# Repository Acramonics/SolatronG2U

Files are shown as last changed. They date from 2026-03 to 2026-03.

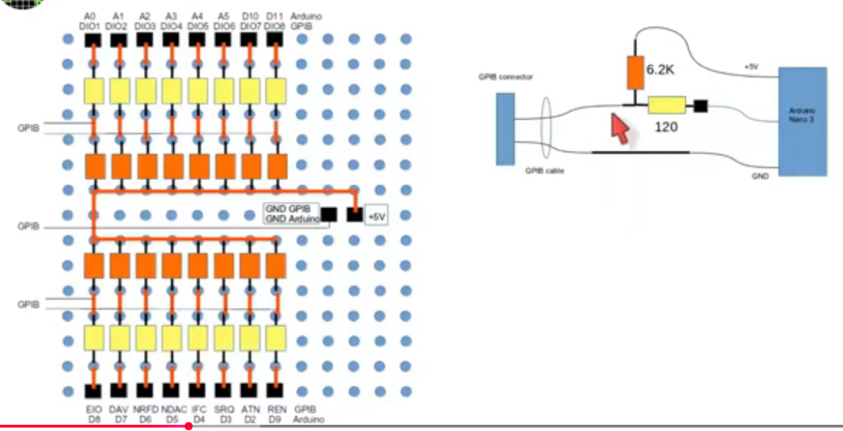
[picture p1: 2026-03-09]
SourceImages/Circuit.png

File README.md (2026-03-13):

G2U
===

Andrew Martin, acramonics, 2026
-------------------------------

`G2U` is a PCB for a GPIB to USB adapter using an Arduino Nano 3.

GPIB is a vendor-neutral interface for controlling equipment and
logging data. While rather outdated, and largely replaced by USB and
Ethernet, some equipment still uses it and there are many second hand
devices (such as multimeters) that use it including the well-regarded
Solartron 7150+.

A video on GPIB (also known as IEEE-488) is on
[YouTube](https://www.youtube.com/watch?v=EEtETGfL_VE) and details are
on [Wikipedia](https://en.wikipedia.org/wiki/GPIB).

### Hardware

The original circuit and software was by Rudolf Reuter and modified by
@TheHWCave. Rudolf's blog, where this was described, doesn't seem to
be available any more (as of March 2026), but @TheHWCave provides a
detailed description of the circuit on
[YouTube](https://www.youtube.com/watch?v=RaLirRvSngk) (see the
screenshots in the `SourceImages` directory).  He builds it on
stripboard and uses an Arduino breakout board, so I decided to create
a PCB instead. He was unable to obtain a PCB-mounted Centronics-style
(*Series 57*) 24-pin connector. These are now easily available from
AliExpress (at about £2.50 with free postage if you spend more than
£8.00), and I have used a PCB-mounted male connector that can plug
straight into the back of the hardware, so you don't need to worry
about cables.

There is another page with a [discussion of creating a GPIB/USB
interface](https://egirland.blogspot.com/2014/03/arduino-uno-as-usb-to-gpib-controller.html),
but note that this uses different pin assignments and different
software.

### Software

@TheHWCave provides the code for the Arduino Nano 3 and a logger
script on [GitHub](https://github.com/TheHWcave/GPIB-to-USB).

He provides an [update
video](https://www.youtube.com/watch?v=DAS1KVU_FaA) which explains how
to address a problem with the Arduino losing its software when the USB
us disconnected, but the GPIB connection is still present. The GPIB
seems to provide some partial power to the Arduino and he provides
instructions on setting a brown-out fuse in software.

I provide a summary of all the necessary information on this page.

The PCB
-------

As is often the case with my PCBs, you will require my
`ACRM_KiCad_Libs` to provide the footprint for the 24-pin male
Centronics-style connector. You will need a version from March 2026 or
later.

Bill of Materials
-----------------

- Arduino ATmega Nano 3.x with USB (ideally USB-C) [1 off]
- 6K2 0.25W resistors (R1-R16) [16 off]
- 120R 0.25W resistors (R17-R32) [16 off]
- Centronics-style 24P 'Series 57' male connector [1 off]

The PCB is 78.05mm x 71.40mm so you will need a plastic case to
accomodate this.  The Centronics-style connector projects from the
board so will need a suitable cutout. The USB connector is set back on
the board, so it's not easy to plug a cable in and out once the board
is in the case, but, since the GPIB sockets are usually at the back of
equipment, the expectation is that the board and the cable will be
left plugged in.

Ardunio to GPIB connections
---------------------------

This table is expanded from a table shown in @TheHWCave's video (see
the screenshot in the `SourceImages` directory) and shows which
connections from the Arduino go to which pins on the GPIB. The Arduino
pins are shown with the pin number (from 1-30) and the position on the
left (L) or right (R) column of pins - both counting from the top.

| Arduino Line | Arduino Pin | | GPIB Pin | Function | ATmega328P |
|---|---|-----|---|---|---|
| A0 | 19/R12 | --- | 1 | DIO1 | (PC0/ADC0) |
| A1 | 20/R11 | --- | 2 | DIO2 | (CP1/ADC1) |
| A2 | 21/R10 | --- | 3 | DIO3 | (PC2/ADC2) |
| A3 | 22/R9 | --- | 4 | DIO4 | (PC3/ADC3) |
| A4 | 23/R8 | --- | 13 | DIO5 | (PC4/ADC4) |
| A5 | 24/R7 | --- | 14 | DIO6 | (PC5/ADC5) |
| D10 | 13/L13 | --- | 15 | DIO7 | (PB2) |
| D11 | 14/L14 | --- | 16 | DIO8 | (PB3(MOSI)) |
| D8 | 11/L11 | --- | 5 | EIO | (PB0) |
| D7 | 10/L10 | --- | 6 | DAV | (PD7) |
| D6 |  9/L9 | --- | 7 | NRFD | (PD6) |
| D5 |  8/L8 | --- | 8 | NDAC | (PD5) |
| D4 |  7/L7 | --- | 9 | IFC | (PD4) |
| D3 |  6/L6 | --- | 10 | SRQ | (PD3) |
| D2 |  5/L5 | --- | 11 | ATN | (PD2) |
| D9 | 12/L12 | --- | 17 | REN | (PB1) |
| GND |  4/L4 | --- | 12,18-24 | GND | |
| GND | 29/R2 | --- | 12,18-24 | GND | |
| +5V | 27/R4 | +5V | | | |
| D1/TX1 |  1/L1 | NC  | | | |
| RX0 |  2/L2 | NC  | | | |
| RESET |  3/L3 | NC  | | | |
| D12 | 15/L15 | NC  | | | |
| VIN | 30/R1 | NC  | | | |
| RESET2 | 28/R3 | NC  | | | |
| A7 | 26/R5 | NC  | | | |
| A6 | 25/R6 | NC  | | | |
| AREF | 18/R13 | NC  | | | |
| +3V3 | 17/R14 | NC  | | | |
| D13 | 16/R15 | NC  | | | |

Note that each GND pin in the GPIB connector is paired with one of the
data lines in a twisted pair. Pin 12 is connected to the cable shield.
See [GPIB on WikiPedia](https://en.wikipedia.org/wiki/GPIB). In this
application, this is rather irrelevant as everything is connected to a
common ground.

The Brown-Out Fuse
------------------

As described above, @TheHWCave provides an [update
video](https://www.youtube.com/watch?v=DAS1KVU_FaA) which explains how
to set the 'brown-out fuse' on the Arduino to prevent it losing its
software.

The 'extended fuse byte' has three bits that set the Brown-Out
Detector voltage level ('BODLEVEL'). When the voltage falls below
this, the chip is disabled.

|Extended Fuse Byte | Bit No | Default Value |
|---|---|---|
|- | 7 | 1 |
|- | 6 | 1 |
|- | 5 | 1 |
|- | 4 | 1 |
|- | 3 | 1 |
|BODLEVEL2 | 2 | 1 (unset) |
|BODLEVEL1 | 1 | 1 (unset) |
|BODLEVEL0 | 0 | 1 (unset) |

The values for the BODLEVEL bits are as follows:

|BODLEVEL 2:0 Fuses | Hex (*)  | Min V | Typ V | Max V | Units |
|---|---|---|---|---|---|
|111 | 0x07 | Off | Off | Off | |
|110 | 0x06 | 1.7 | 1.8 | 2.0 | V |
|101 | 0x05 | 2.5 | 2.7 | 2.9 | V |
|100 | 0x04 | 4.1 | 4.3 | 4.5 | V |
|011 | 0x03 | Reserved | Reserved | Reserved | |
|010 | 0x02 | Reserved | Reserved | Reserved | |
|001 | 0x01 | Reserved | Reserved | Reserved | |
|000 | 0x00 | Reserved | Reserved | Reserved | |

(*) Since bits 3 to 7 are not used, these can all be set to zero and
the Hex values reflect that.

By default the fuse is set to #FF, the BODLEVEL bits are therefore set
to binary 111 which means the brown-out fuse is switched off.

@TheHWCave selects a BODLEVEL of 4.1V (minimal) so sets the
fuse to binary 100 (#04) for 4.1V cutoff.

Instructions on how to do this are provided below.

Software Installation
---------------------

You will need:

- A USB cable to connect your computer to your Arduino Nano
- An ICSP programmer with a 6-pin header adapter to connect to the
  Nano.  There are instructions online to use another Arduino for this
  purpose or you can buy a standalone programmer such as the USBASP
  programmers available from Amazon (amongst other places).

You will need the software available from
https://github.com/TheHWcave/GPIB-to-USB

Using this is explained in the video at
https://www.youtube.com/watch?v=RaLirRvSngk

### Step 1: The Arduino IDE

Install the Arduino IDE as described on the [Arduino Web
Site](https://support.arduino.cc/hc/en-us/articles/360019833020-Download-and-install-Arduino-IDE)

### Step 2: Configure the IDE for the Arduino Nano ATmega chip you are using [OPTIONAL]

Different Arduinos use different chips which have different signature
bytes and this needs to match the programmer:

Chip        | Byte 0x000 | Byte 0x001 | Byte 0x002
------------|------------|------------|------------
ATmega328   | 0x1E       | 0x95       | 0x14
ATmega328P  | 0x1E       | 0x95       | 0x0F
ATmega328PB | 0x1E       | 0x95       | 0x16

If the configuration doesn't match your chip then, for example, the
Arduino IDE may call AVRDude (used to set the fuse) expecting to find
an ATmega328P, but AVRDude finds an ATmega328PB and stops.

The configuration can be set in a configuration file or by manually
re-running the failed command, but correcting for the appropriate
chip. (See instructions below.)

If using Linux, the easest thing to do is create configuration file:
`~/.avrduderc` containing:

```
part parent "m328"
    id                  = "m328p";
    desc                = "ATmega328P";
    signature           = 0x1e 0x95 0x14;
    ocdrev              = 1;
;
```
setting the `id`, `desc` and `signature` as required depending on what
ATmega chip you have with signature bytes set as per the table above.

Alternatively you can allow AVRDude from the IDE to fail and then run
the fixed command manually as described below.

### Step 3: Setting the Brown-Out Fuse

*I will write a more detailed version when I have verified this on a
couple of Arduino Nano boards. This is largely in note form!*

As described above, you will need a second Arduino, or an ICSP
programmer spported by the Arduino IDE, to set the fuse. The IDE runs
the AVRDude software to perform the programming of the Brown-Out Fuse.

*To set the fuse from the Arduino IDE, proceed as follows --- to be written*

See:
- https://forum.arduino.cc/t/is-there-brown-out-detection-for-arduino-uno/124777/18
- https://electronics.stackexchange.com/questions/229189/atmega328p-how-is-brown-out-detection-supposed-to-work
- https://forum.arduino.cc/t/unable-to-set-fuses-on-atmega328p-using-avrdude-in-command-prompt-windows/1067499/5

Set the IDE to run in verbose mode so you can see what it is doing as
[described
here](https://support.arduino.cc/hc/en-us/articles/4407705216274-Use-verbose-output-in-the-Arduino-IDE)

If you have configured the IDE properly, then it should work with no
errors.  If you haven't then the AVRDude software will fail since the
chip's signature doesn't match what the software expected. The
workaround for this is described in @TheHWCave's video at
https://www.youtube.com/watch?v=DAS1KVU_FaA and summarized below.

If AVRDude fails, simply copy the failed command from the upload
window and run it from the command line instead, correcting the
errornous chip type. For example, assuming the Arduino IDE is
configured for an ATmega328P and your Nano has an ATmega328PM and
assuming that the IDE is installed in a directory pointed to by the
environment variable `$ARDUINO` (e.g. `$HOME/arduino-1.8.9`), you
might see the failed command to be:

```
$ARDUINO/hardware/tools/avr/bin/avrdude \
   -C$ARDUINO/hardware/tools/avr/etc/avrdude.conf \
   -v -patmega328p \
   -cusbasp -Pusb -e -Ulock:w:0x3F:m -Uefuse:w:0xF4:m \
   -Uhfuse:w:0xDA:m -Ulfuse:w:0xFF:m
```
and you would modify this to
```
$ARDUINO/hardware/tools/avr/bin/avrdude \
   -C$ARDUINO/hardware/tools/avr/etc/avrdude.conf \
   -v -patmega328pb \
   -cusbasp -Pusb -e -Ulock:w:0x3F:m -Uefuse:w:0xF4:m \
   -Uhfuse:w:0xDA:m -Ulfuse:w:0xFF:m
```
(note the change in the 3rd line) and run it from the command line

### Step 4: Restoring the bootloader

Setting the fuse erases the memory, so you then need to restore the bootloader.

Instructions on doing this from the IDE are [described here](https://support.arduino.cc/hc/en-us/articles/4841602539164-Burn-the-bootloader-on-UNO-Mega-and-classic-Nano-using-another-Arduino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)

Alternatively, you can do it from the command line using AVRDude:

```
~/arduino-1.8.9/hardware/tools/avr/bin/avrdude \
   -C~/arduino-1.8.9/hardware/tools/avr/etc/avrdude.conf \
   -v -patmega328pb \
   -cusbasp -Pusb -Uflash:w:./optiboot_atmega328.hex
```

This also allows the latest bootloader to be downloaded and installed.
See

- https://forum.arduino.cc/t/how-do-i-install-optiboot-on-the-newest-arduino-ide/345443
- https://github.com/Optiboot/optiboot

(The latest, as of March 2026, is
https://github.com/Optiboot/optiboot/releases/download/v8.0/package_optiboot_optiboot-additional_index.json)

### Step 5: Installing the Arduino software

You can then remove the in-circuit programmer and upload the
GPIB-to-USB software sketch in the normal way from the Arduino IDE
through the USB cable and with the newly installed boot loader.

*To be written.*

Future plans
------------

In future, I may do an SMD version to minimize the size and weight!

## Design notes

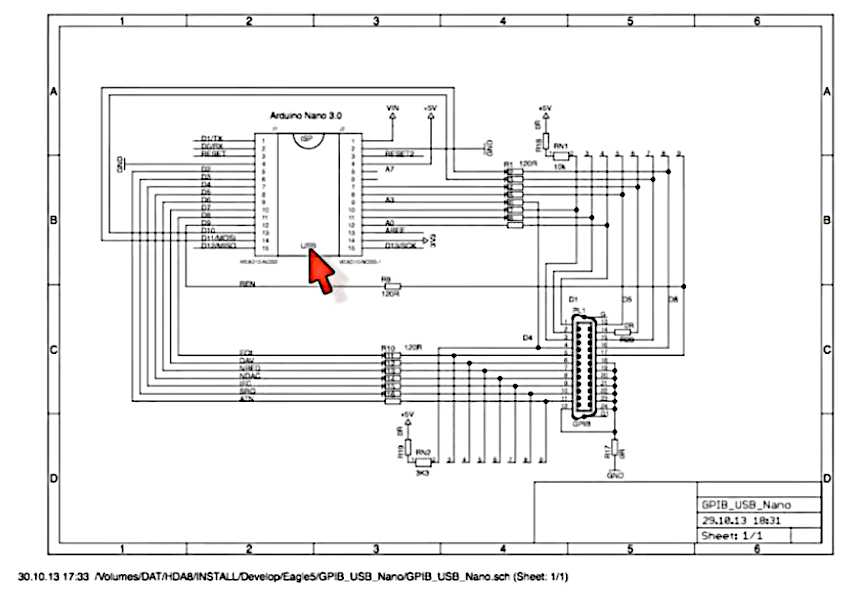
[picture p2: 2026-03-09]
SourceImages/Schematic.png

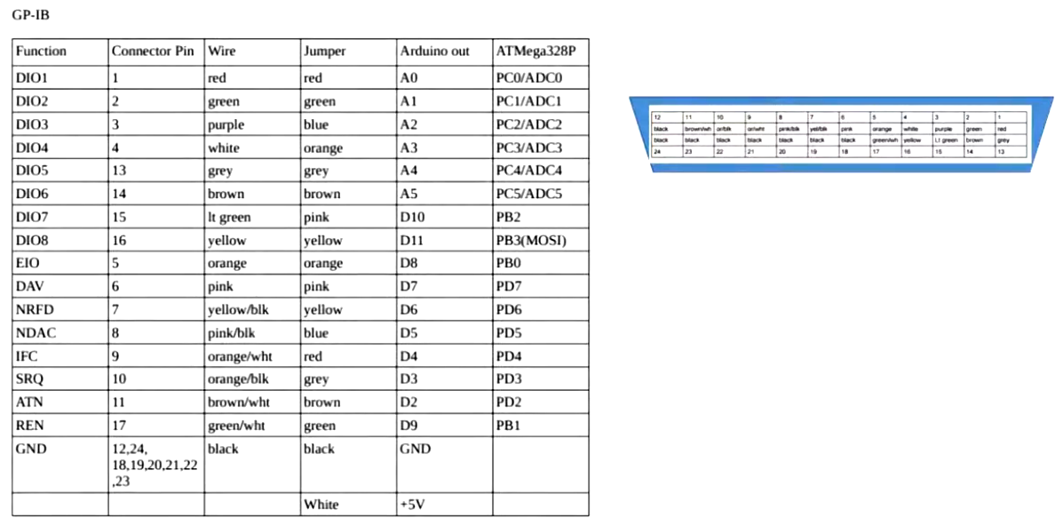
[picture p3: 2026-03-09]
SourceImages/ConnectionTable.png

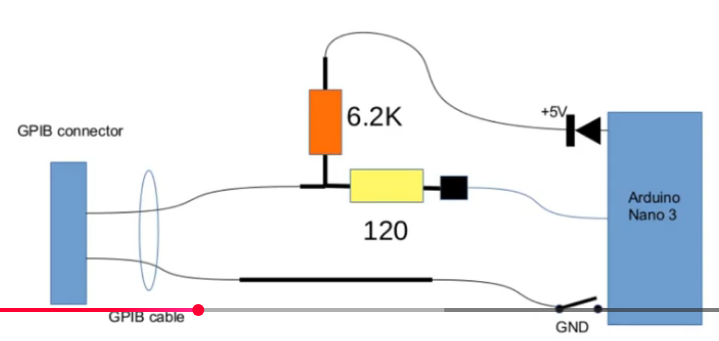
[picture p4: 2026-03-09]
SourceImages/DiodeAndSwitch.png

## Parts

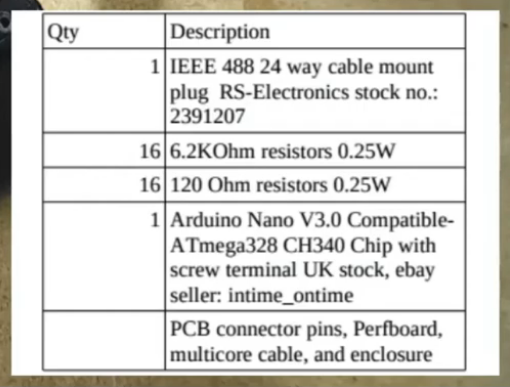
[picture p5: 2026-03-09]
SourceImages/BOM.png

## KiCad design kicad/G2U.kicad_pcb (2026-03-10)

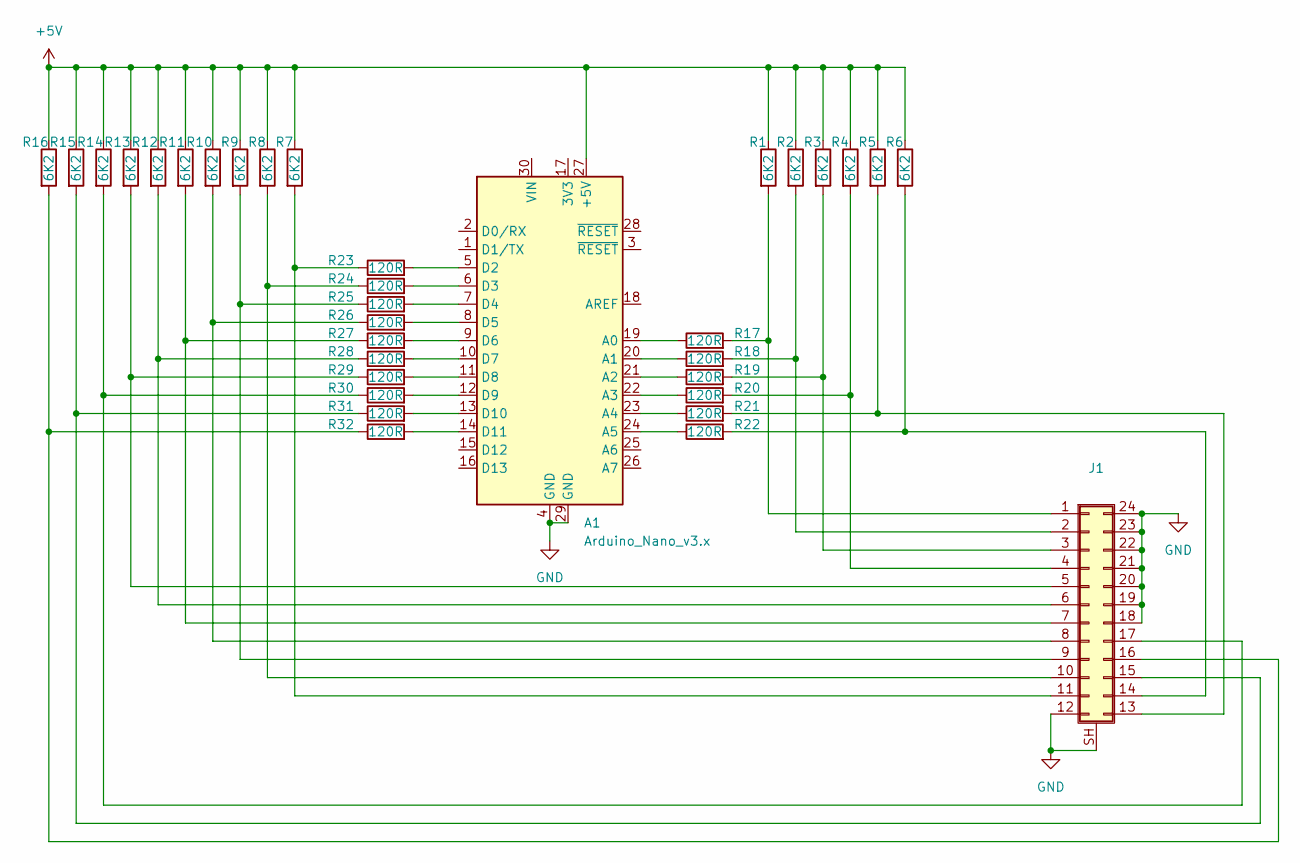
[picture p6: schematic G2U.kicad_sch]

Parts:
A1: Arduino_Nano_v3.x; Arduino_Nano
J1: Conn_02x12_Counter_Clockwise_Shielded; Connector_CentronicsMale-2x12_P2.16mm_P4.29_Horizontal
R1, R2, R3, R4, R5, R6, R7, R8, R9, R10, R11, R12, R13, R14, R15, R16: 6K2; R_Axial_DIN0207_L6.3mm_D2.5mm_P10.16mm_Horizontal
R17, R18, R19, R20, R21, R22, R23, R24, R25, R26, R27, R28, R29, R30, R31, R32: 120R; R_Axial_DIN0207_L6.3mm_D2.5mm_P10.16mm_Horizontal

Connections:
+5V: A1.27 (+5V), R1.1, R2.1, R3.1, R4.1, R5.1, R6.1, R7.1, R8.1, R9.1, R10.1, R11.1, R12.1, R13.1, R14.1, R15.1, R16.1
GND: A1.4 (GND), A1.29 (GND), J1.12, J1.18, J1.19, J1.20, J1.21, J1.22, J1.23, J1.24, J1.SH (Shield)
unnamed: A1.19 (A0), R17.1
unnamed: A1.20 (A1), R18.1
unnamed: A1.21 (A2), R19.1
unnamed: A1.22 (A3), R20.1
unnamed: A1.23 (A4), R21.1
unnamed: A1.24 (A5), R22.1
unnamed: A1.5 (D2), R23.2
unnamed: A1.6 (D3), R24.2
unnamed: A1.7 (D4), R25.2
unnamed: A1.8 (D5), R26.2
unnamed: A1.9 (D6), R27.2
unnamed: A1.10 (D7), R28.2
unnamed: A1.11 (D8), R29.2
unnamed: A1.12 (D9), R30.2
unnamed: A1.13 (D10), R31.2
unnamed: A1.14 (D11), R32.2
unnamed: J1.1, R1.2, R17.2
unnamed: J1.2, R2.2, R18.2
unnamed: J1.3, R3.2, R19.2
unnamed: J1.4, R4.2, R20.2
unnamed: J1.5, R13.2, R29.1
unnamed: J1.6, R12.2, R28.1
unnamed: J1.7, R11.2, R27.1
unnamed: J1.8, R10.2, R26.1
unnamed: J1.9, R9.2, R25.1
unnamed: J1.10, R8.2, R24.1
unnamed: J1.11, R7.2, R23.1
unnamed: J1.13, R5.2, R21.2
unnamed: J1.14, R6.2, R22.2
unnamed: J1.15, R15.2, R31.1
unnamed: J1.16, R16.2, R32.1
unnamed: J1.17, R14.2, R30.1

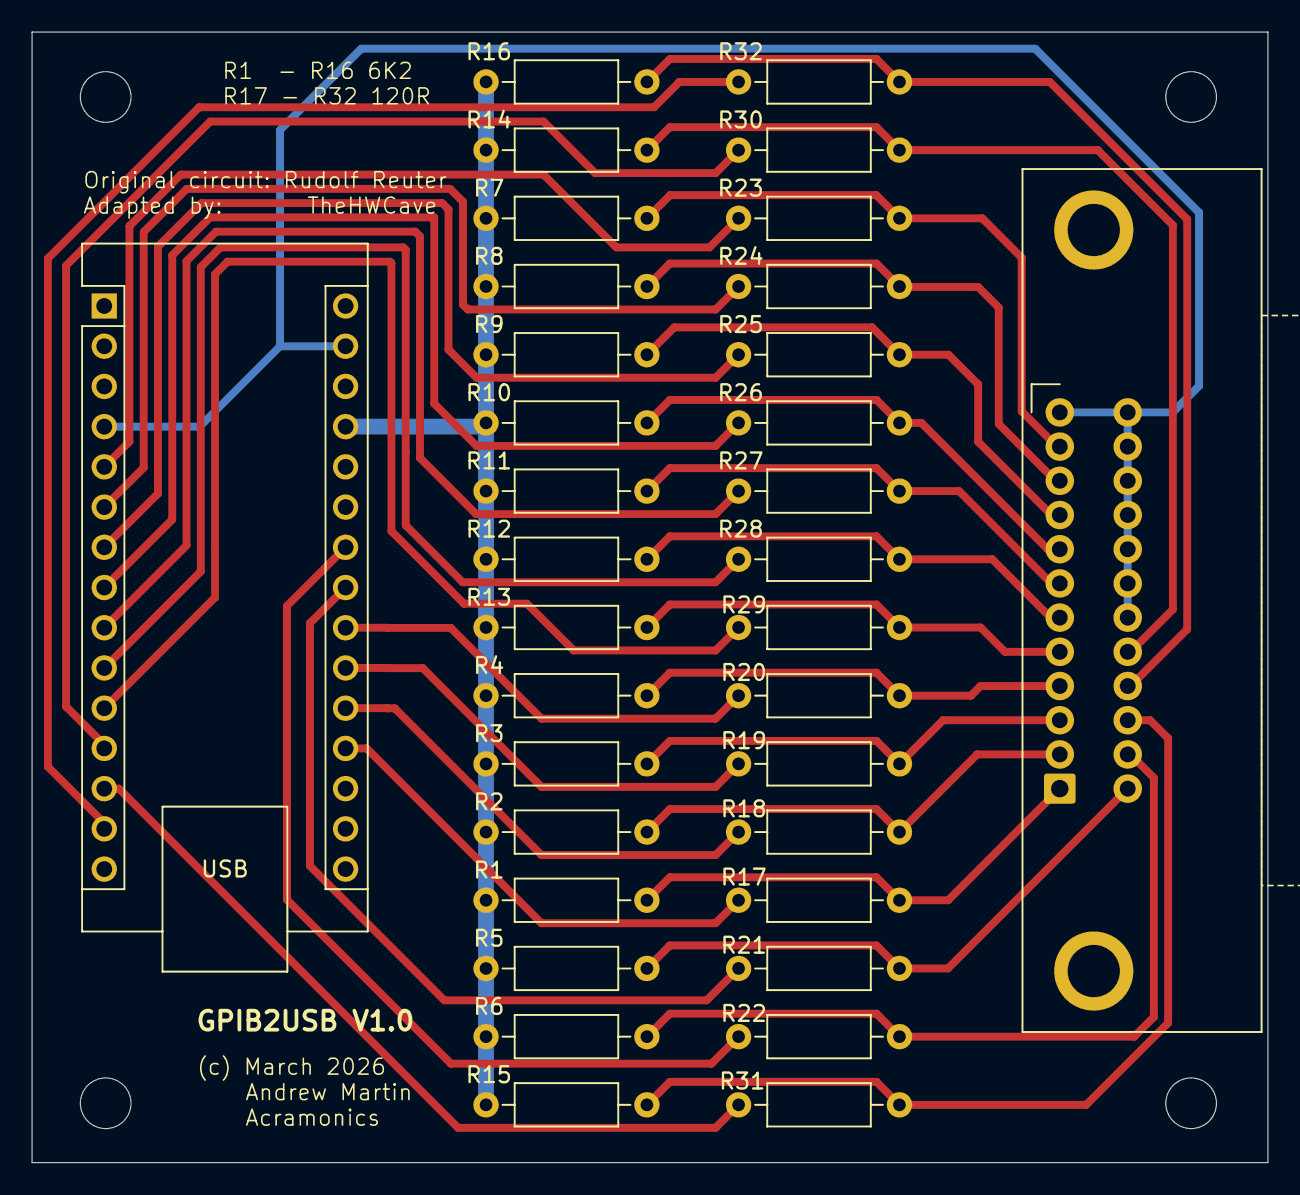
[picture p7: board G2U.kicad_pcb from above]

Board: 2 copper layers, 78.0 x 71.4 mm, 34 parts (0 on the bottom side), 34 nets.

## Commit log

2026-03-09 Schematic completed
    [SolatronG2U.kicad_pcb, SolatronG2U.kicad_sch]
2026-03-09 First bash at PCB
    [SolatronG2U.kicad_pcb]
2026-03-09 Added new footprint for Centronics
    [SolatronG2U.kicad_pcb]
2026-03-10 Finished V1.0 PCB and updated README
    [G2U.kicad_pcb, G2U.kicad_sch, SolatronG2U.kicad_pcb]
